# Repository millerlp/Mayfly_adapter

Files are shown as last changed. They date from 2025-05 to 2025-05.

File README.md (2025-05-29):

# Mayfly_adapter
A circuit board for interfacing 8 analog sensors with an EnviroDIY Mayfly v1.1 data logger. 
This can be used to monitor multiple simple analog voltage inputs. Using the software library
linked below, the user can cycle through 8 inputs of an analog multiplexer (TMUX1208PWR, Texas Instruments) and send the chosen
voltage signal to the analog-to-digital convertor of the Mayfly data logger. The board also has
an 8-channel port expander (PCA9557PWR) that can be used to toggle the SLEEP pin of an attached analog
sensor like the Allegro A1395 Hall effect sensor that this board is designed for. 

As of 2025, the RevB hardware files are functional and in use. These can be used to 
produce a printed circuit board that can be populated with the parts listed in the
file Mayfly_adapter_v1p1_revB_parts.xlsx. 

While the circuit board contains circuits for reading 8 multiplexed analog inputs and
8 multiplexed I2C lines, only the analog input lines are implemented in the associated
library found at [https://github.com/millerlp/Allegro_A139x_8channel_mux](https://github.com/millerlp/Allegro_A139x_8channel_mux). 

Note that this 8-Channel library also relies on a modified library for the PCA9557 library 
found here: [https://github.com/millerlp/pca9557](https://github.com/millerlp/pca9557)

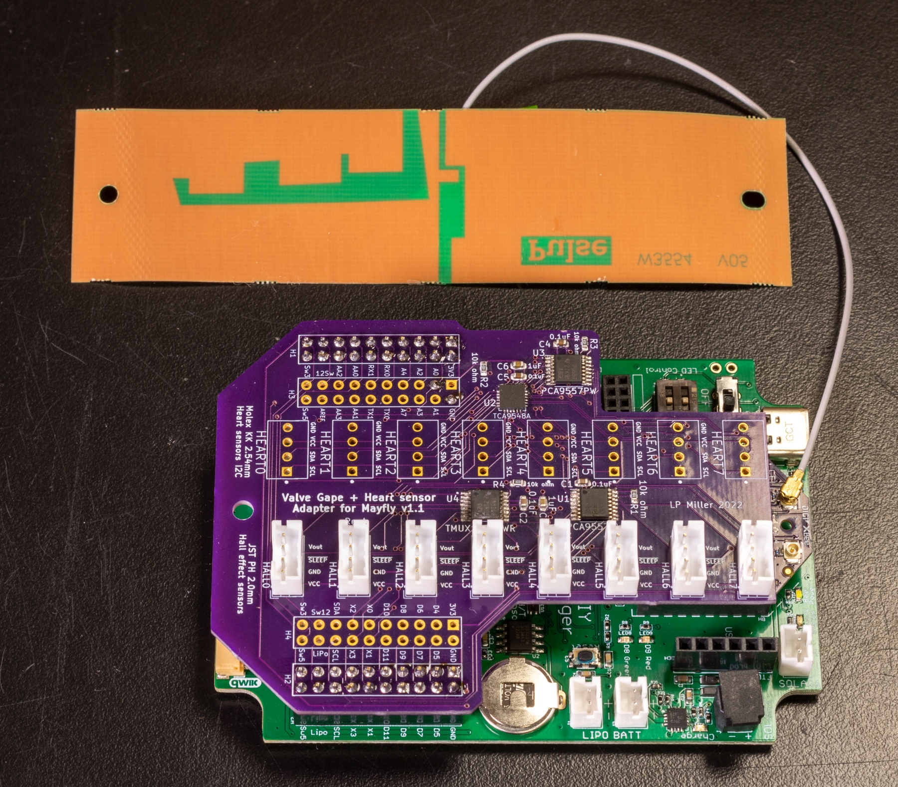
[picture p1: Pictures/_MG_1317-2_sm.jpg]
Image of a Mayfly adapter circuit board attached to an EnviroDIY Mayfly v1.1 data logger


On the bottom of the Mayfly data logger board, some of the solder jumpers should be 
modified: 

On solder jumper 19 (SJ19), move the solder blob from 12 to 13. 
On solder jumper 16 (SJ16), place a blob of solder (activates modem power LED - white)
On solder jumper 17 (SJ17), place a blob of solder (activates modem network indicator LED - blue)

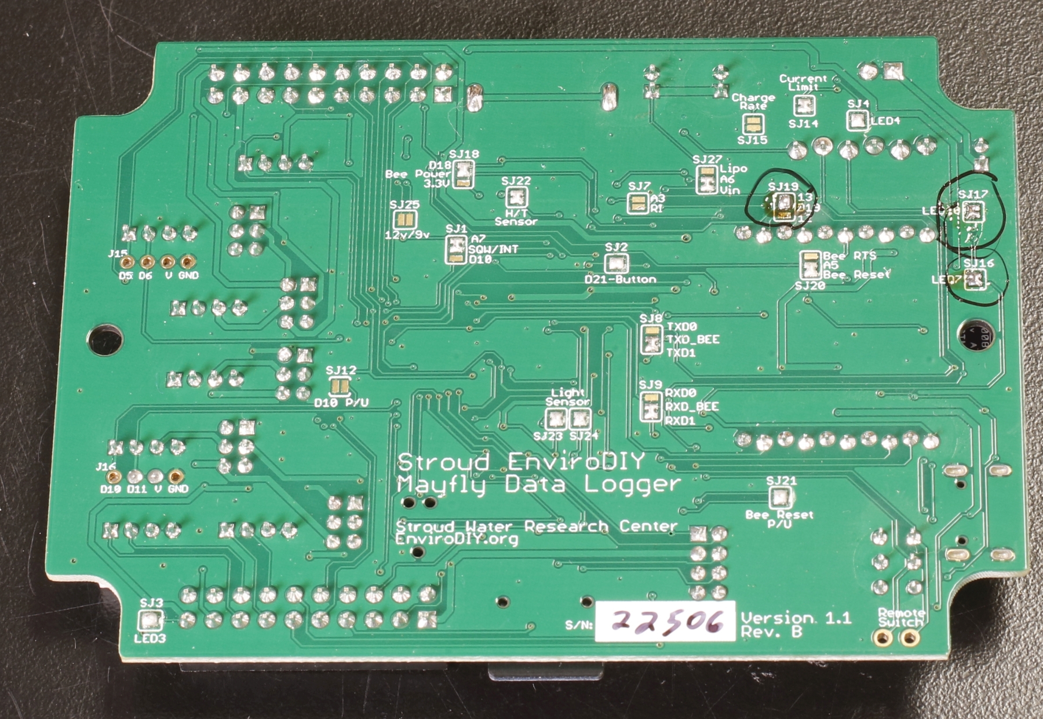
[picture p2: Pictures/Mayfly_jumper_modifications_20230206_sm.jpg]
Image of the bottom of a Mayfly data logger with solder jumpers circled


Developed by Luke Miller

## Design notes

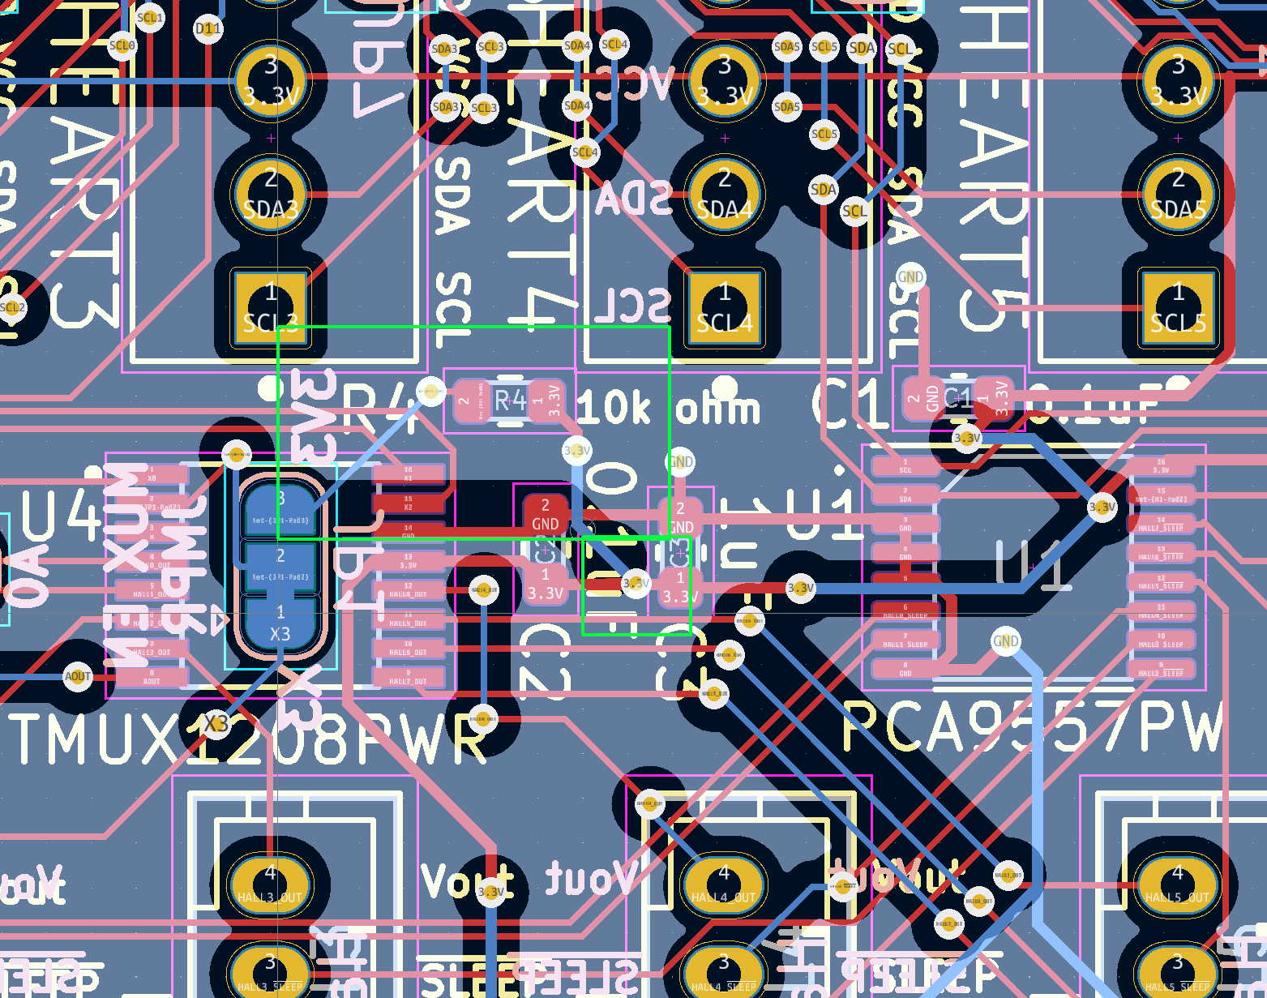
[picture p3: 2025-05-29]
Pictures/Mayfly_adapter_RevA_error_initial_run.png

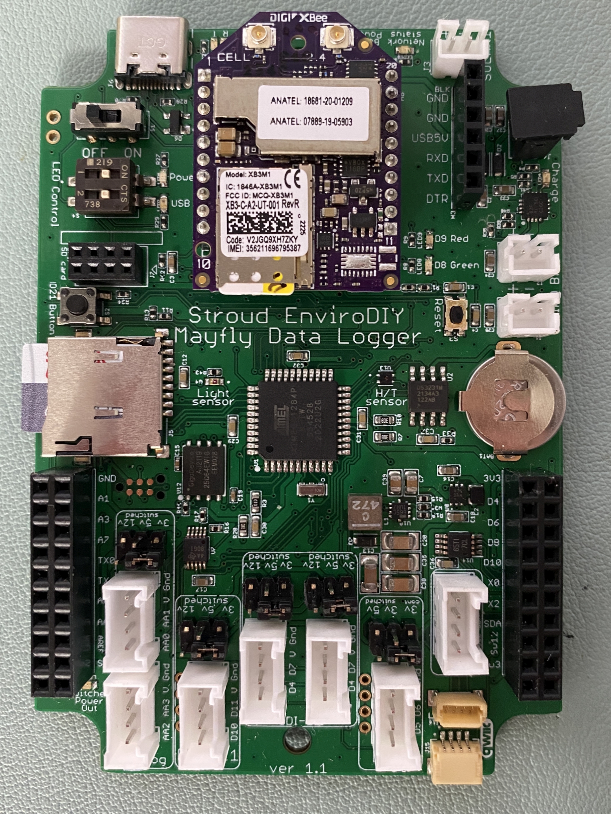
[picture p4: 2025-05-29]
Pictures/Mayfly_v1p1_board.jpg

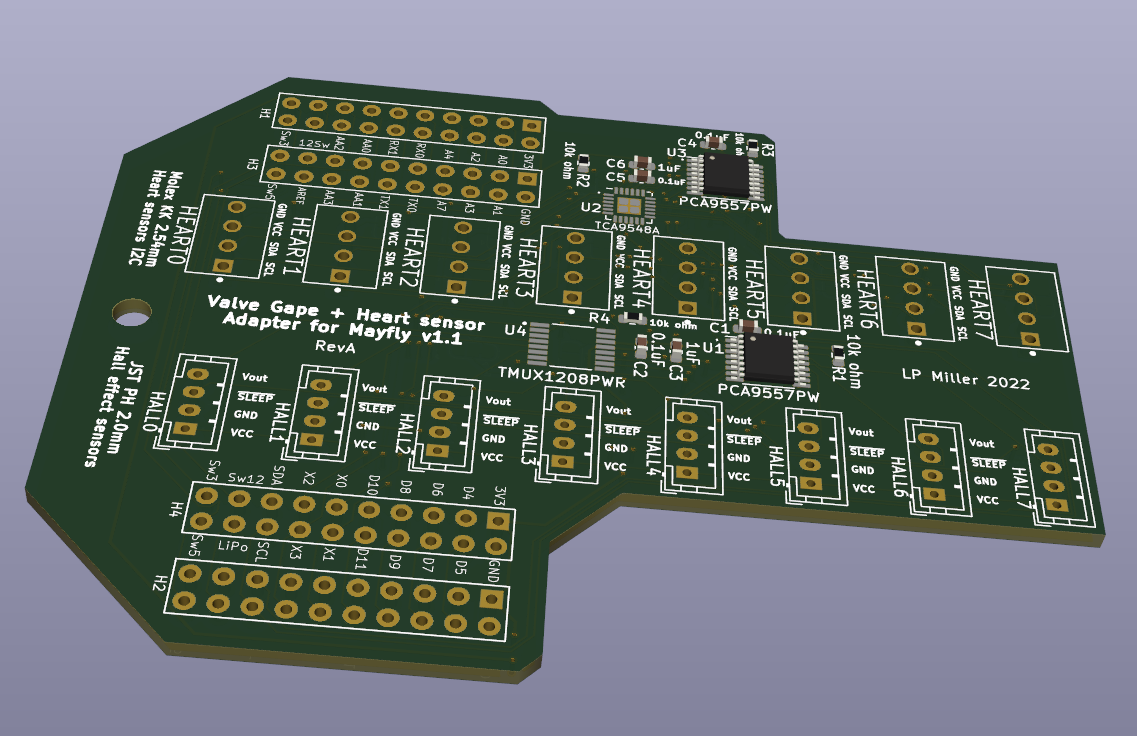
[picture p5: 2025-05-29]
Pictures/Mayfly_adapter_v1p1_render.png

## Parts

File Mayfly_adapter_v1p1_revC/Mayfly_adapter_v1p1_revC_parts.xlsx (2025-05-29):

 | Mayfly_adapter_v1p1_RevB
Schematic designator | Digikey.com materials | Manufacturer PN | Digikey PN | Qty | Unit Price | Per-board price
U1, U3 | PCA9577 I2C port expander 16-TSSOP | PCA9577PW | 296-20978-2-ND | 2 | $1.280 | $2.56
U4 | TMUX1208PWR 8-ch analog multiplexer 16-TSSOP | TMUX1208PWR | 296-51847-2-ND | 1 | $0.781 | $0.78
U2 | TCA9548AMRGER 8-ch I2C multiplexer, VQFN package | TCA9548AMRGER | 296-TCA9548ARGERQ1TR-ND | 1 | $1.96 | $1.96
Hall0-7 | JST_PH_B4B-PH-K_04x2.00mm_Straight | B4B-PH-K-S(LF)(SN) | 455-1706-ND | 8 | $0.22 | $1.76
Heart0-7 | Molex KK 4-pin header thru-hole 2.54mm | 22112042 | WM2702-ND | 8 | $0.65 | $5.20
C1,C2,C4,C5 | Capacitor 0.1uF - 0603 ceramic 25V X7R | CL10B104KA8NNNC | 1276-1006-1-ND | 4 | $0.10 | $0.40
C3,C6 | CAP CER 1UF 16V X7R 0603 | CL10B105MO8NNWC | 1276-6524-1-ND | 2 | $0.09 | $0.18
R1, R2, R3, R4 | RES SMD 10K OHM 5% 1/10W 0603 | ERJ-3GEYJ103V | P10KGCT-ND | 3 | $0.10 | $0.30
R5, R6 | RES SMD 100K OHM 5% 1/10W 0603
H1, H2 | Male HEADER VERT 40POS 2-row 2.54MM, breakaway | PRPC020DFBN-RC | S2221EC-20-ND | 1 | $1.21 | $1.21
H3,H4 | Female Header 20POS 2x10 0.1 GOLD PCB | PPPC102LFBN-RC | S6106-ND | 2 | $1.14 | $2.28
 | JST 4-pin connector housing, female | PHR-4 | 455-1164-ND | 8 | $0.10 | $0.80
 | JST crimp-on female connector 24-30AWG | SPH-002T-P0.5S | 455-1127-1-ND | 32 | $0.10 | $3.20
 |  |  |  |  | Subtotal | $20.64 | Subtotal | $0.00
 | Heart rate sensor modules |  |  | 8 | $14.94 | $119.52
 | CABLE GLAND 2.5-6.5MM PG7 POLY - Altech | 5308 507 | 1920-1056-ND | 8 | $1.39 | $11.12
 | O-ring 1/8 width dash number 206 - McMasterCarr https://www.mcmaster.com/4061t228/ | 4061T228 | 4061T228
 | Digi 4G LTE CAT-M1 modem | XB3-C-A2-UT-001 | 602-2169-ND | 1 | $81.68 | $81.68
 | EnviroDIY Mayfly v1.1 (Amazon) |  | https://www.amazon.com/EnviroDIY-Mayfly-Logger-Arduino-Compatible/dp/B01F9B4WCG/ref=sr_1_1 | 1 | $120.00 | $120.00
 | Solar Panel - 5 Watt | Adafruit Industries 5367 | 1528-5367-ND | 1 | $43.69 | $43.69
 | Li-Ion battery 4400mAh | Adafruit Industries 354 | 1528-1834-ND | 1 | $17.96 | $17.96
 | Watertight box Integra Enclosures, clear top | H10084HC-6P-WHT | 2321-H10084HC-6P-WHT-ND | 1 | $98.18 | $98.18
 |  |  |  |  | Subtotal | $492.15 | Subtotal | $152.88
 | SIM card (360 MB / year minimum)
 | 4-conductor cable USB-2.0 28gauge 0.150" diameter, 1000ft spool | 2725-2828-BL-01000-A | CN230B-1000-ND | 1 | $152.88 | $152.88 | 1 | $152.88
 | 1/4" heat shrink semi-rigid 4ft, black, moisture-proof | ‎SCL-1/4-0-STK‎ | ‎484-SCL-1/4-0-STK-ND‎ | 1 | 7.73

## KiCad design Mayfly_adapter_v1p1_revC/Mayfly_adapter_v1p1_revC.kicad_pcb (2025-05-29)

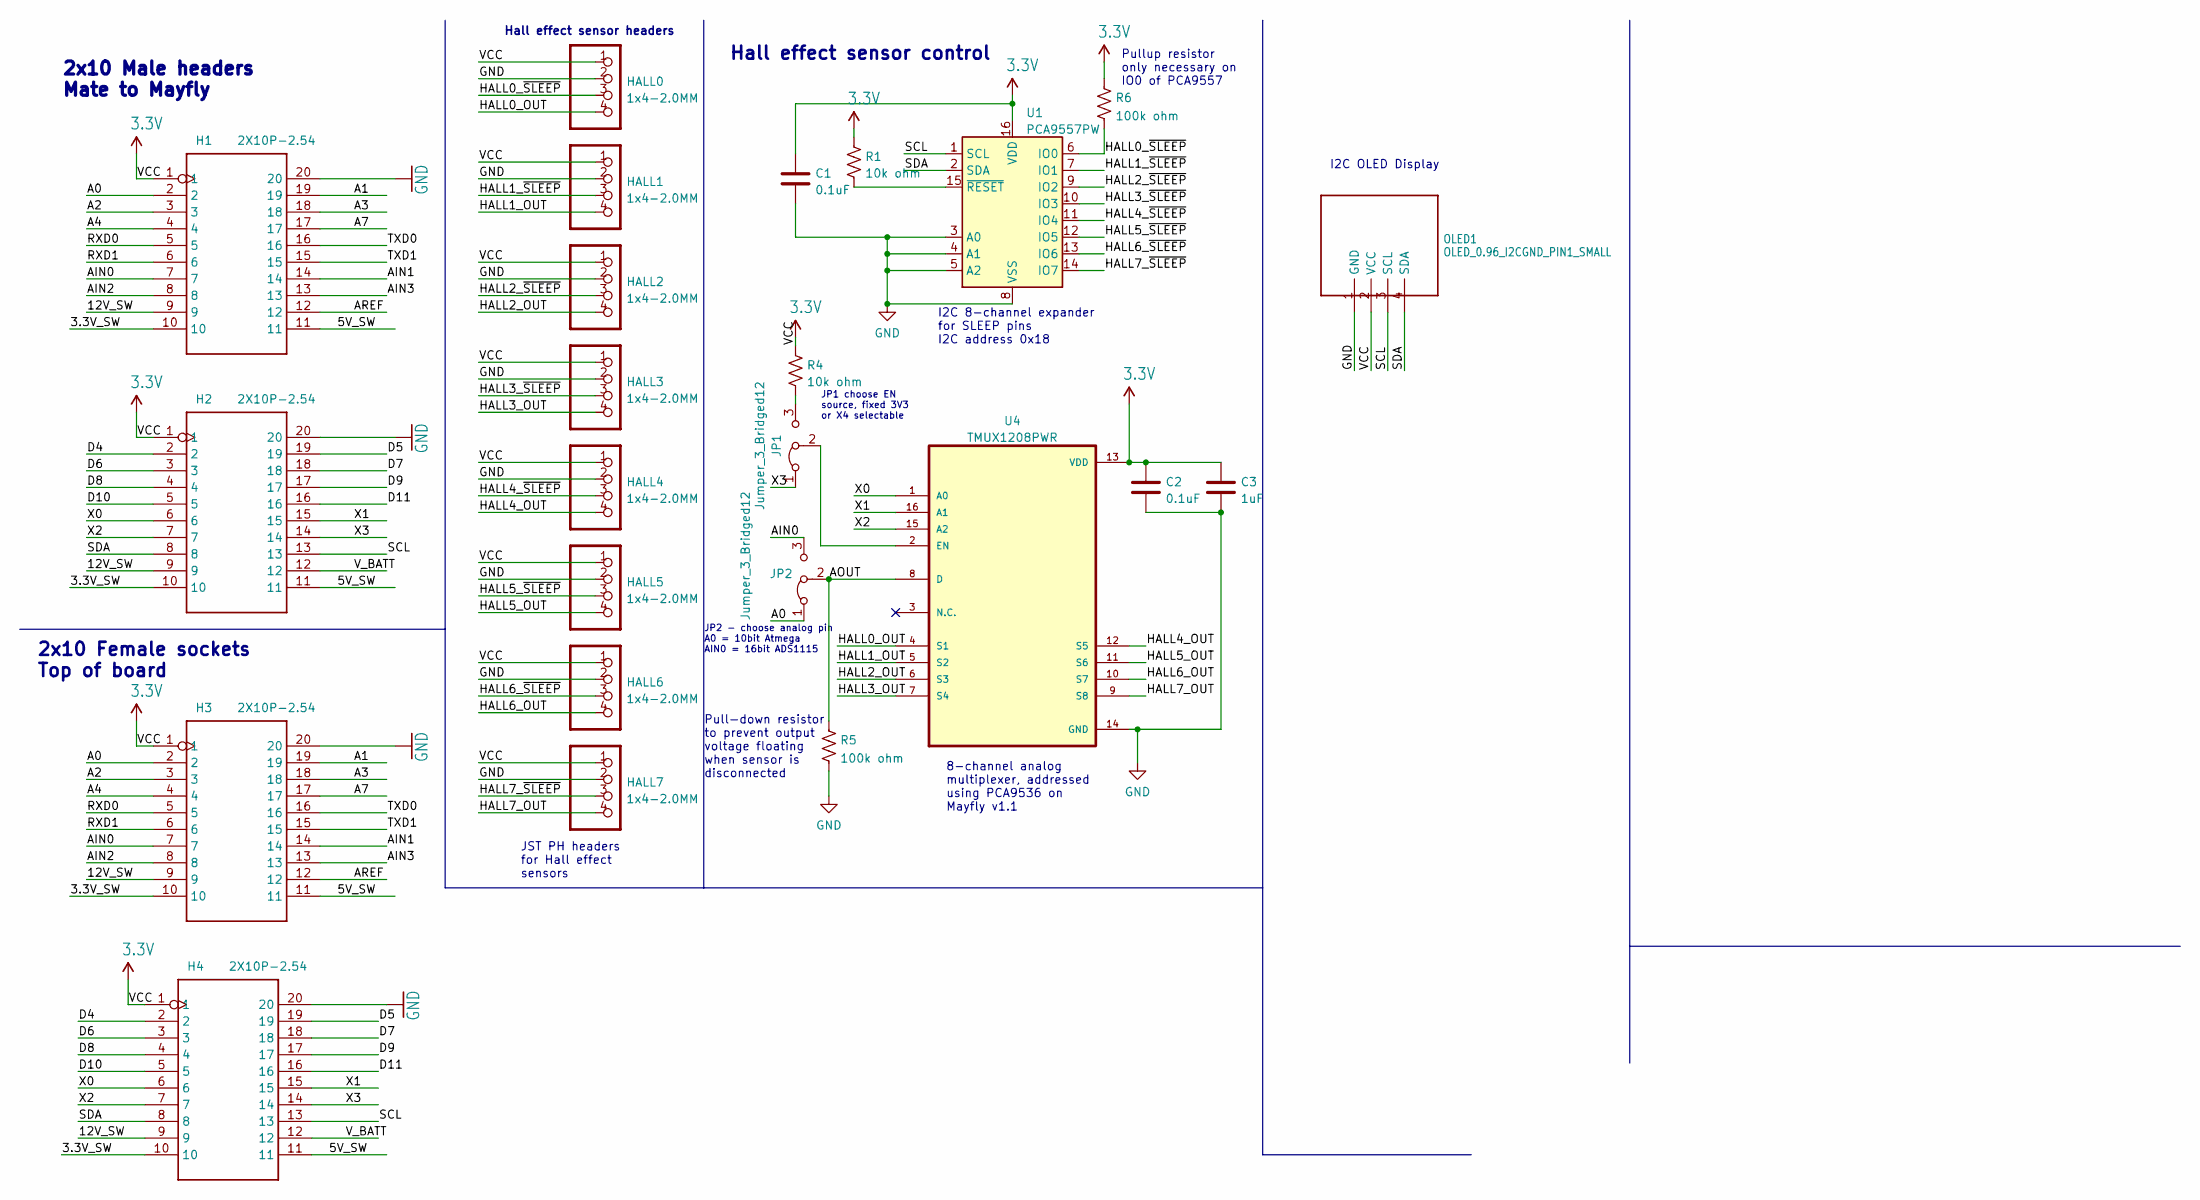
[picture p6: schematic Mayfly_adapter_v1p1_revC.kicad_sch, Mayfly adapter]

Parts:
C1, C2: 0.1uF; C_0603_1608Metric
C3: 1uF; C_0603_1608Metric
H1, H2, H3, H4: 2X10P-2.54; H2X10-2.54
HALL0, HALL1, HALL2, HALL3, HALL4, HALL5, HALL6, HALL7: 1x4-2.0MM; JST_PH_B4B-PH-K_04x2.00mm_Straight
JP1, JP2: Jumper_3_Bridged12; SolderJumper-3_P1.3mm_Bridged12_RoundedPad1.0x1.5mm
OLED1: OLED_0.96_I2CGND_PIN1_SMALL; Display_128x64_096_I2C
R1, R4: 10k ohm; R_0603_1608Metric
R5, R6: 100k ohm; R_0603_1608Metric
U1: PCA9557PW; TSSOP-16_4.4x5mm_P0.65mm
U4: TMUX1208PWR; SOP65P640X120-16N

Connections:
3.3V: C1.1, C2.1, C3.1, H1.1, H2.1, H3.1, H4.1, HALL0.1, HALL1.1, HALL2.1, HALL3.1, HALL4.1, HALL5.1, HALL6.1, HALL7.1, OLED1.2 (VCC), R1.1, R4.1, R6.1, U1.16 (VDD), U4.13 (VDD)
/3.3V_SW: H1.10, H2.10, H3.10, H4.10
/5V_SW: H1.11, H2.11, H3.11, H4.11
/12V_SW: H1.9, H2.9, H3.9, H4.9
/A0: H1.2, H3.2, JP2.1 (A)
/A1: H1.19, H3.19
/A2: H1.3, H3.3
/A3: H1.18, H3.18
/A4: H1.4, H3.4
/A7: H1.17, H3.17
/AIN0: H1.7, H3.7, JP2.3 (B)
/AIN1: H1.14, H3.14
/AIN2: H1.8, H3.8
/AIN3: H1.13, H3.13
/AOUT: JP2.2 (C), R5.1, U4.8 (D)
/AREF: H1.12, H3.12
/D4: H2.2, H4.2
/D5: H2.19, H4.19
/D6: H2.3, H4.3
/D7: H2.18, H4.18
/D8: H2.4, H4.4
/D9: H2.17, H4.17
/D10: H2.5, H4.5
/D11: H2.16, H4.16
/HALL0_OUT: HALL0.4, U4.4 (S1)
/HALL0_~SLEEP: HALL0.3, R6.2, U1.6 (IO0)
/HALL1_OUT: HALL1.4, U4.5 (S2)
/HALL1_~SLEEP: HALL1.3, U1.7 (IO1)
/HALL2_OUT: HALL2.4, U4.6 (S3)
/HALL2_~SLEEP: HALL2.3, U1.9 (IO2)
/HALL3_OUT: HALL3.4, U4.7 (S4)
/HALL3_~SLEEP: HALL3.3, U1.10 (IO3)
/HALL4_OUT: HALL4.4, U4.12 (S5)
/HALL4_~SLEEP: HALL4.3, U1.11 (IO4)
/HALL5_OUT: HALL5.4, U4.11 (S6)
/HALL5_~SLEEP: HALL5.3, U1.12 (IO5)
/HALL6_OUT: HALL6.4, U4.10 (S7)
/HALL6_~SLEEP: HALL6.3, U1.13 (IO6)
/HALL7_OUT: HALL7.4, U4.9 (S8)
/HALL7_~SLEEP: HALL7.3, U1.14 (IO7)
/RXD0: H1.5, H3.5
/RXD1: H1.6, H3.6
/SCL: H2.13, H4.13, OLED1.3 (SCL), U1.1 (SCL)
/SDA: H2.8, H4.8, OLED1.4 (SDA), U1.2 (SDA)
/TXD0: H1.16, H3.16
/TXD1: H1.15, H3.15
/V_BATT: H2.12, H4.12
/X0: H2.6, H4.6, U4.1 (A0)
/X1: H2.15, H4.15, U4.16 (A1)
/X2: H2.7, H4.7, U4.15 (A2)
/X3: H2.14, H4.14, JP1.1 (A)
GND: C1.2, C2.2, C3.2, H1.20, H2.20, H3.20, H4.20, HALL0.2, HALL1.2, HALL2.2, HALL3.2, HALL4.2, HALL5.2, HALL6.2, HALL7.2, OLED1.1 (GND), R5.2, U1.3 (A0), U1.4 (A1), U1.5 (A2), U1.8 (VSS), U4.14 (GND)
unnamed: JP1.3 (B), R4.2
unnamed: JP1.2 (C), U4.2 (EN)
unnamed: R1.2, U1.15 (~RESET)

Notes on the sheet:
Hall effect sensor headers
JST PH headers for Hall effect sensors
Pullup resistor only necessary on IO0 of PCA9557
JP1 choose EN source, fixed 3V3 or X4 selectable
2x10 Female sockets Top of board
JP2 - choose analog pin A0 = 10bit Atmega AIN0 = 16bit ADS1115
I2C OLED Display
I2C 8-channel expander for SLEEP pins I2C address 0x18
Hall effect sensor control
8-channel analog multiplexer, addressed using PCA9536 on Mayfly v1.1
Pull-down resistor to prevent output voltage floating when sensor is disconnected
2x10 Male headers Mate to Mayfly

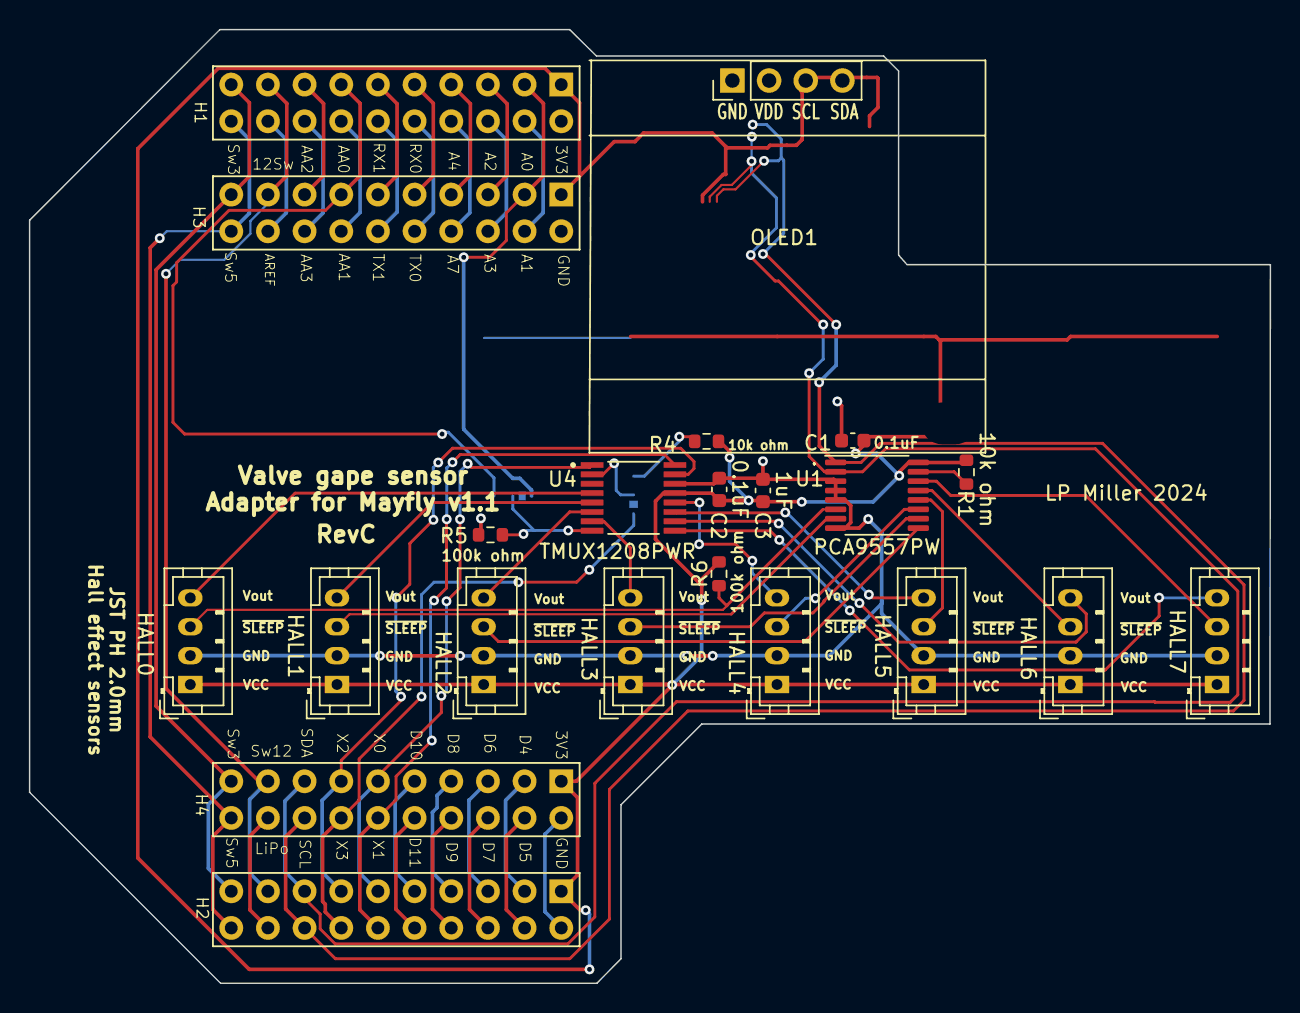
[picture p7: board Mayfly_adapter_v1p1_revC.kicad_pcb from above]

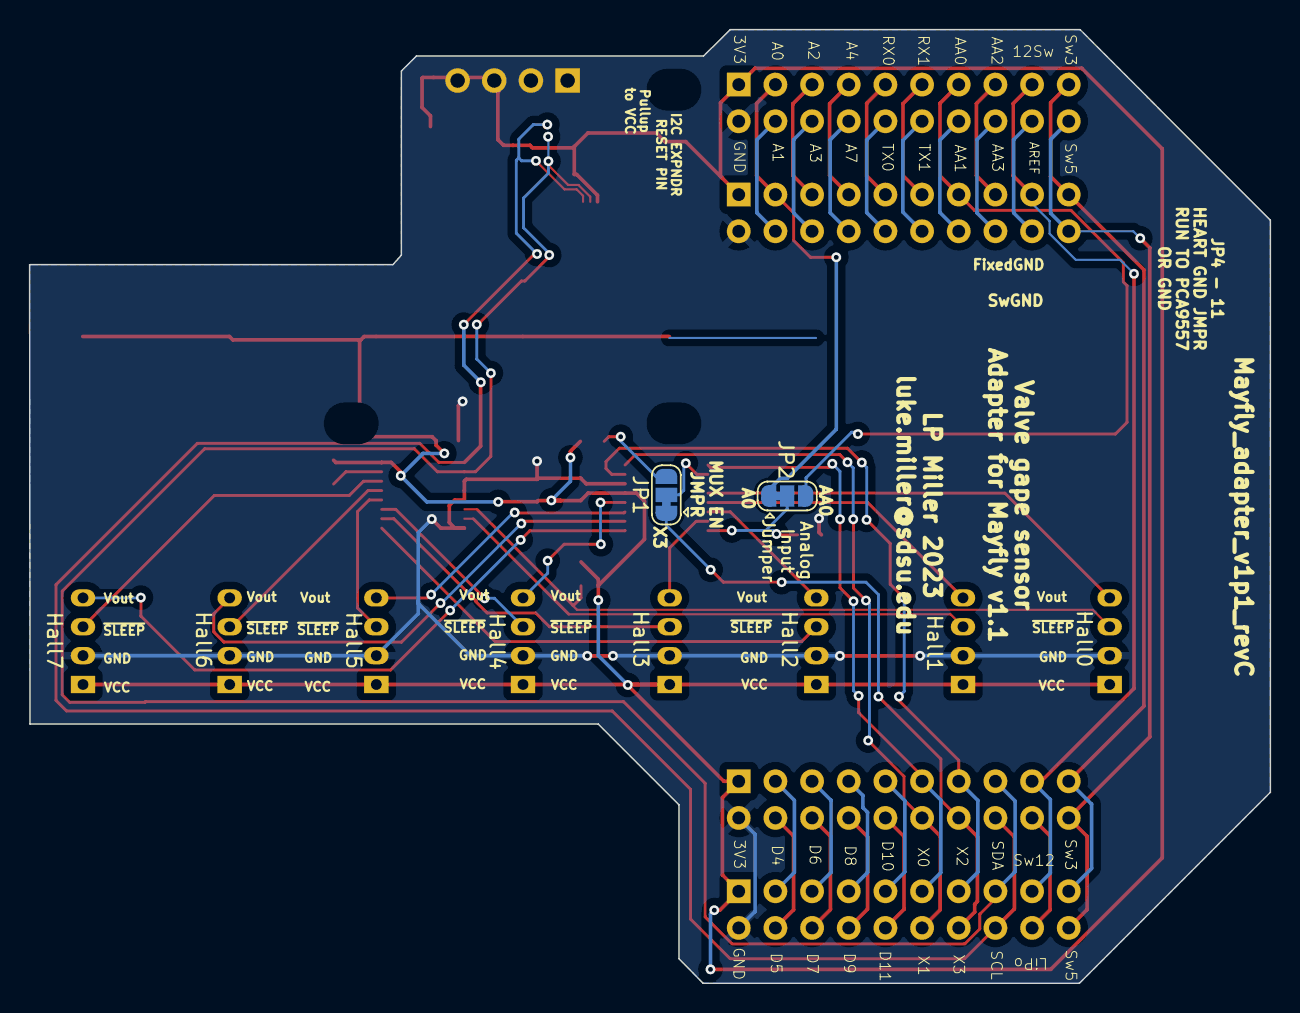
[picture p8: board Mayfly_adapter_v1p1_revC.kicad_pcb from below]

Board: 2 copper layers, 86.0 x 66.1 mm, 24 parts (2 on the bottom side), 55 nets.

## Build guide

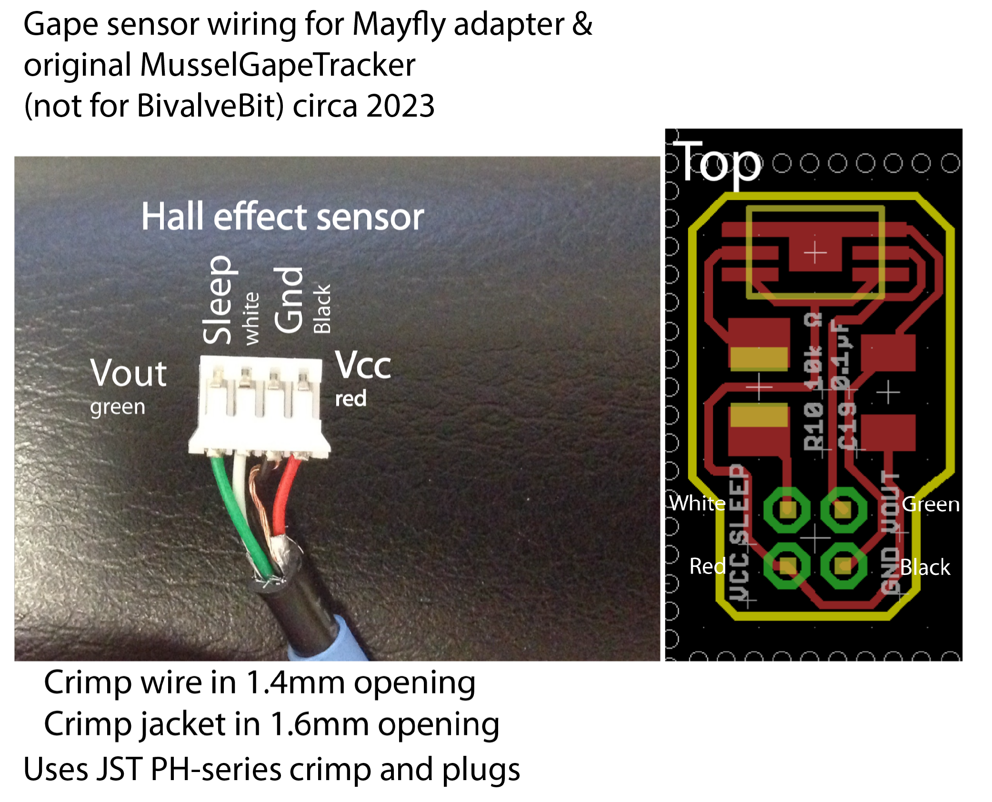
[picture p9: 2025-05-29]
Pictures/Mayfly_gape_wiring.png

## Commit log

2025-05-29 Prototype images
2025-05-29 Rev A
    [Mayfly_adapter_v1p1_revA.kicad_pcb, Mayfly_adapter_v1p1_revA.kicad_sch, Mayfly_adapter_v1p1_revA_parts.xlsx]
2025-05-29 Rev B - working prototype
    This version was in use 2023-2024
    [Mayfly_adapter_v1p1_revB.kicad_pcb, Mayfly_adapter_v1p1_revB.kicad_sch, Mayfly_adapter_v1p1_revB_parts.xlsx]
2025-05-29 Rev C is not complete - do not use yet
    Revision C is still a work in progress and is not functional.
    [Mayfly_adapter_v1p1_revC.kicad_pcb, Mayfly_adapter_v1p1_revC.kicad_sch, Mayfly_adapter_v1p1_revC_parts.xlsx]
2025-05-29 Lower case file extension
